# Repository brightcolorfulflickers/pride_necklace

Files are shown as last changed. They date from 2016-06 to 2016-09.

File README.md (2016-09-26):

# pride_necklace
A Neopixel necklace to celebrate LGBT pride.

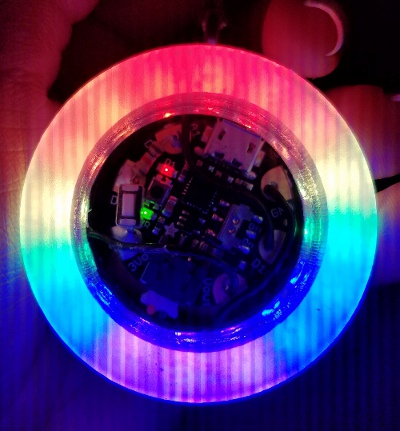
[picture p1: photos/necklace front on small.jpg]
Rainbow Flag Necklace


## Overview
I made this necklace to celebrate LGBT pride month. It's based on [this Adafruit tutorial](https://learn.adafruit.com/gemma-hoop-earrings/overview), but I modified it heavily. It adds a button so that the user can cycle through different animations. Full instructions are below.

Thank you to Adafruit for posting this project on their [blog](https://blog.adafruit.com/2016/06/26/a-neopixel-necklace-to-celebrate-lgbt-pride-her_nerdiness-pride2016/)!

## Tools Required

I used a laser cutter, a 3d printer, and a soldering iron.

## Parts Used

Electronic parts:
- [Adafruit Gemma](https://www.adafruit.com/product/1222)
- [16 Neopixel Ring](https://www.adafruit.com/product/1463)
- [150 mAh battery](https://www.adafruit.com/product/1317)
- [Slim button](https://www.adafruit.com/products/1489)
- 10k resistor
- 26 AWG stranded wire

Other parts:
- E6000 adhesive
- Acrylic: [3/16" clear](http://www.mcmaster.com/#8560K163), [1/8" clear](http://www.mcmaster.com/#8560K239), [1/8" frosted](http://www.ebay.com/itm/272185258220)
- PLA filament
- [Glue-on pendant bail](https://www.etsy.com/transaction/1154709693)
- Chain of your choice - buy at any craft store

## Instructions

For the electronic part, mostly follow the Adafruit tutorial linked above. However, I made the following modifications. Be sure to carefully measure out wire lengths so that there is a little slack on the wires but not too much.
- Solder D1 to Neopixel data in.
- Solder the button between 3V and D0.
- Solder the resistor between D0 and D2.
- Be sure to solder to the 5V on the Neopixel ring right under the "Power 5V DC" label and the ground to the ground right under the "Ground" label.

Upload the code: pridenecklace.ino. This version has the rainbow flag, but you can modify this to make your own flags. I've included code for the bisexual and trans pride flags as well; see prideoutfit.ino. The main limitation is the low memory of the Gemma.

Laser cut the following parts:
- Cut "necklace back.svg" on the 1/8" clear acrylic.
- Cut "necklace front.svg" -- one copy of the circle on the 1/8" frosted acrylic, and two copies of the circle on the 3/16" clear acrylic. (Or you can 3D print a diffuser instead - see below.)

These files were created in Inkscape. I simply used the dimensions provided by Adafruit, if you would like to re-create them.

3D print the 150 mAh battery case. I just did a "fast print" in Cura to generate my gcode. You can also 3D print a diffuser cover for the Neopixel ring. I created the files in OpenSCAD and they're parametric, so you can edit them if you want. V1 was my original print but the wire slots are too small and there's not enough room for the battery wires at the bottom, so V2 should be an improvement. Also, you don't have to glue it on - it should just press fit on.

Use the E6000 to glue the small round piece to the back of the Gemma. Glue the ring with cutouts for the solder joints to the back of the Neopixel ring. Allow that to set and dry overnight.

Next, glue the pendant bail to the acrylic on the back on the Neopixel ring. Be sure to line up the bail with the top pixel, which is between the Adafruit flower and the Data Input solder joint. Also glue the battery case to the back of the acrylic on the Gemma. Line up the top opening of the case with the flat top cutout of the acrylic.

Glue the two remaining clear acrylic circles together, and glue the frosted acrylic circle on top of that. Be sure to spread a thin, even layer of the glue. Be sure all three layers are well-aligned. Let dry for several hours.

Carefully spread glue on the top white part of the pixels on the ring. Press the 3-layer acrylic ring on top and let dry.

If you want, you can shorten the battery wires. Cut, re-solder, and heat shrink.

## Photos

Don't mind the weird lines! They're an artifact of the Neopixel refresh rate.

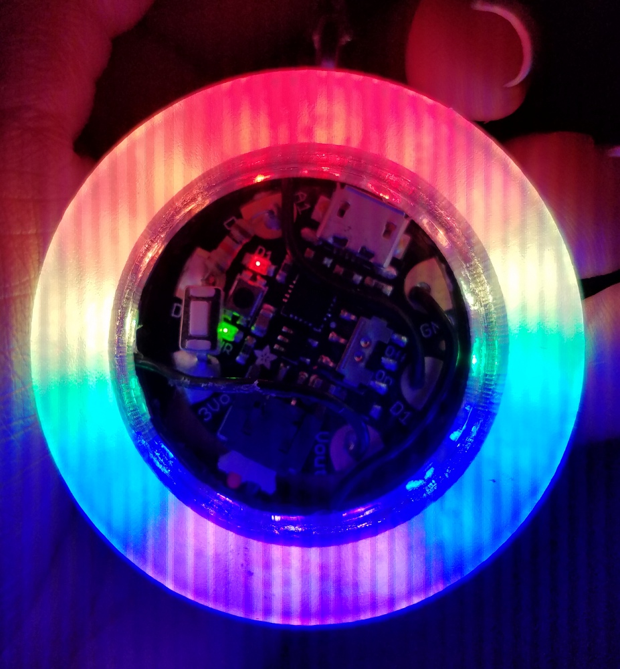
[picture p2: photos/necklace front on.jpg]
Rainbow Flag Necklace

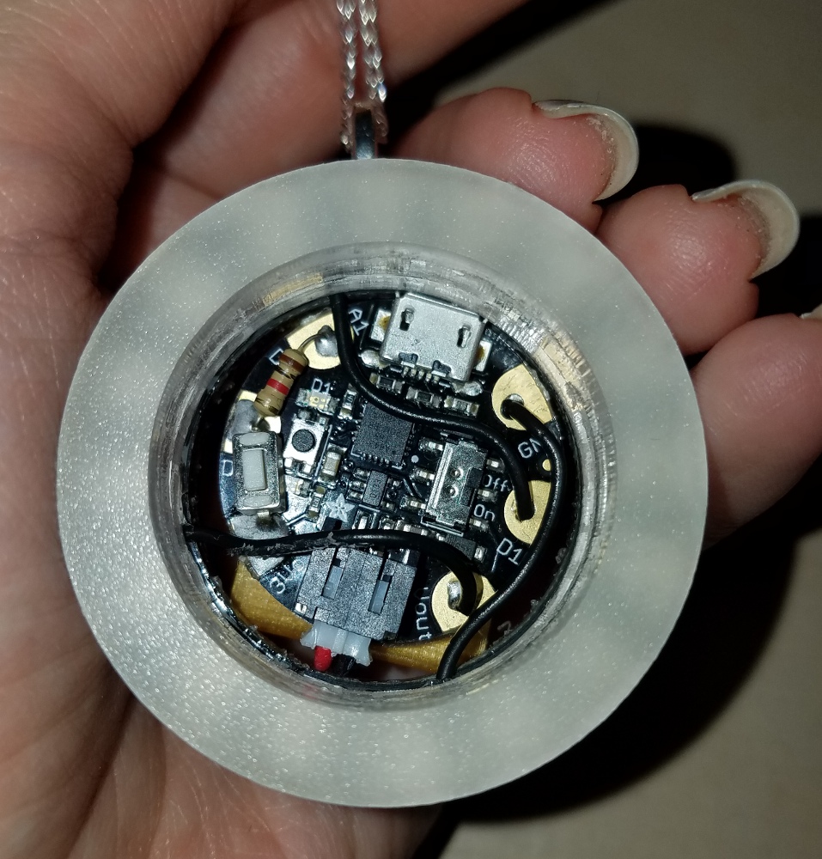
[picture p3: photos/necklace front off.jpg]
Rainbow Flag Necklace (off)

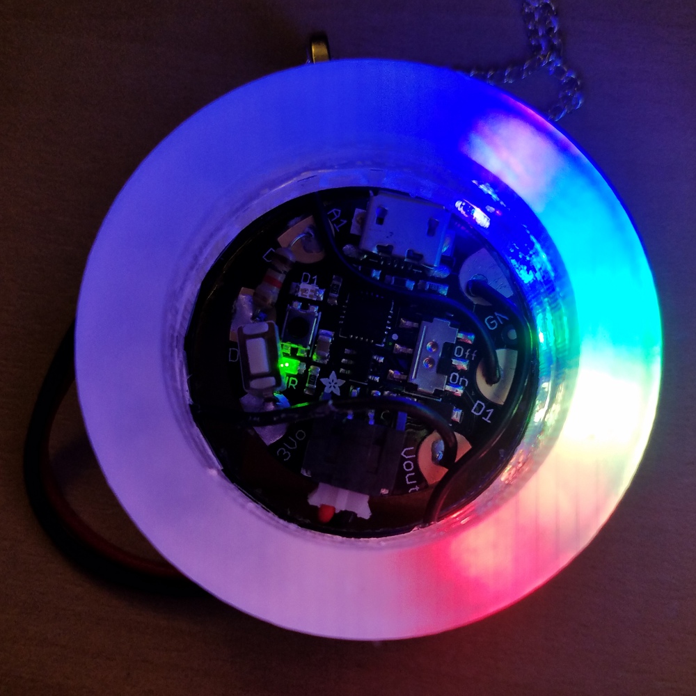
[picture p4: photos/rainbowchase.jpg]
Rainbow Flag Necklace (animation)

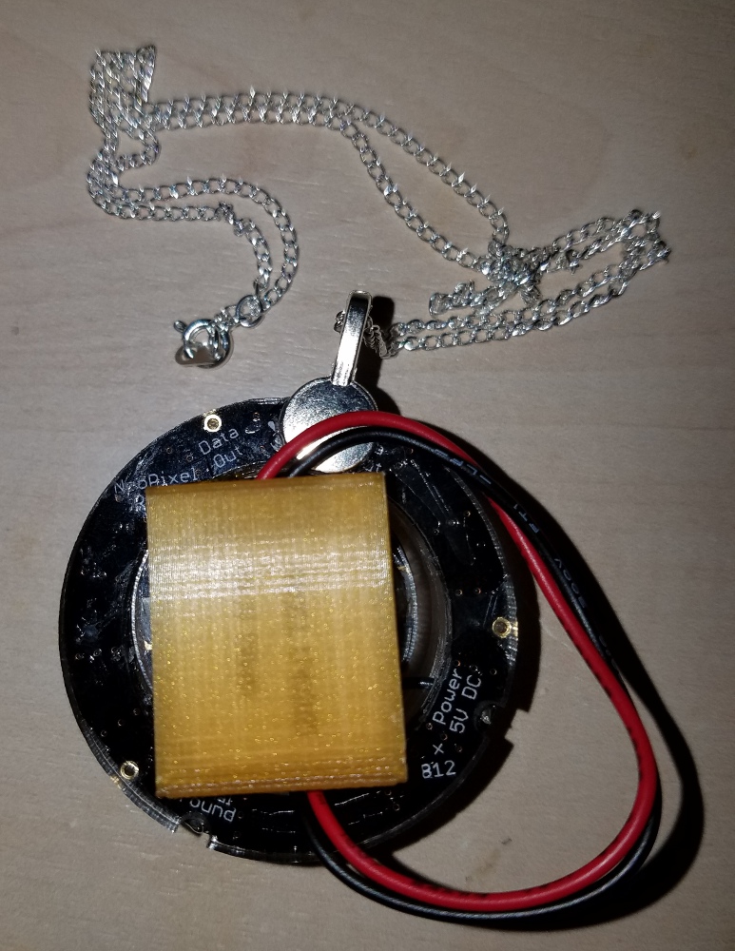
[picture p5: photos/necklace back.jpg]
Rainbow Flag Necklace (back)


For more process photos, see my [tumblr](http://brightcolorfulflickers.tumblr.com/tagged/pride-necklace).

## VARIANT: Pride Outfit

I also made a slightly more risqué version that I call the [pride outfit](http://brightcolorfulflickers.tumblr.com/tagged/pride-outfit). I used two Neopixel rings and a Gemma. I sewed the rings and Gemma into a cloth bikini with one ring on each side. That version uses the prideoutfit.ino code. Simply solder the two rings to the same pin and they will both receive the same data.

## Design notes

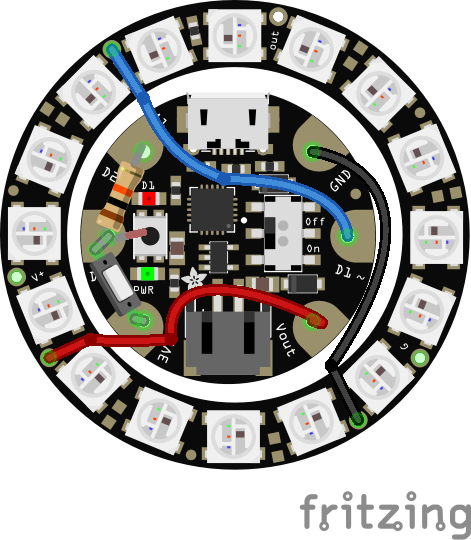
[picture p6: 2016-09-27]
schematic/pride necklace schematic.png

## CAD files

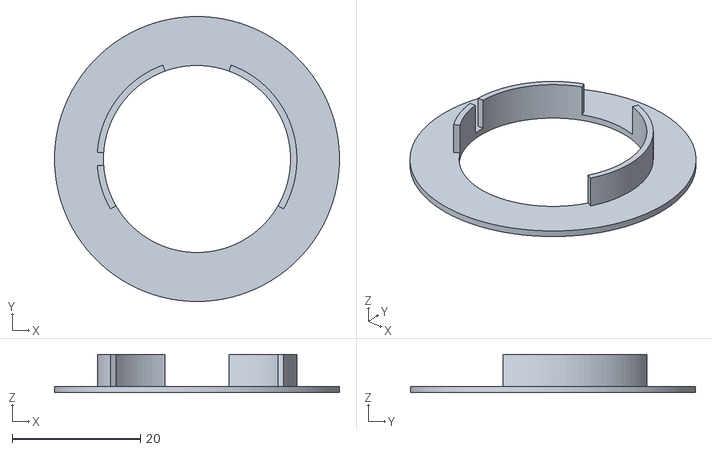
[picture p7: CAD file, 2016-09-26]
3dprint/16 neopixel cover v2.stl
44.5 x 44.5 x 6.00

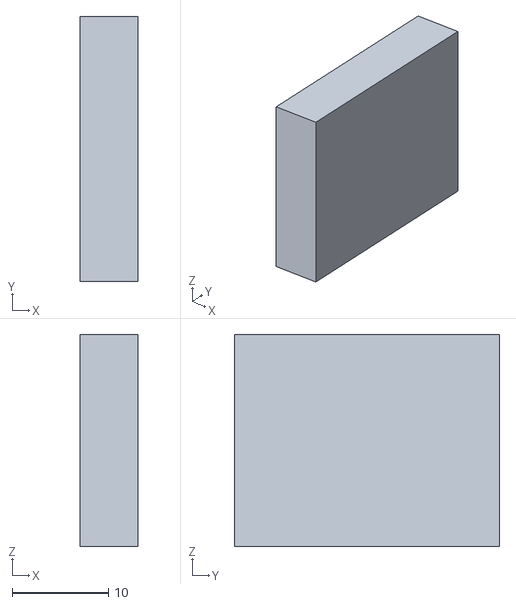
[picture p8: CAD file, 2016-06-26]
3dprint/150mAh battery case.stl
6.00 x 27.5 x 22.0

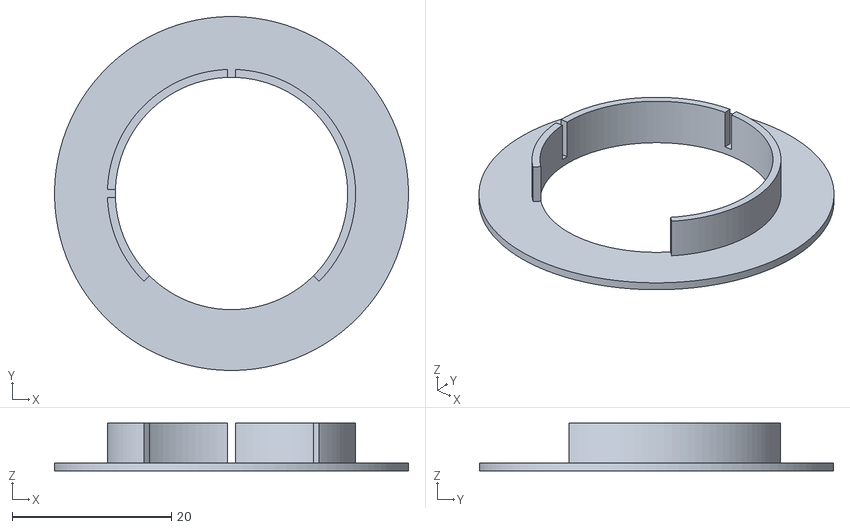
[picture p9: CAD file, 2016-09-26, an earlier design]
3dprint/16 neopixel cover v1.stl
44.5 x 44.5 x 6.00

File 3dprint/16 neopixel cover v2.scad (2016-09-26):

// This design is a cover for Adafruit's 16-Neopixel ring combined with the Gemma microcontroller into a necklace.
// Author: brightcolorfulflickers - instagram, tumblr, github
// September 2016

ring_h = 5; // height of the inner ring perpendicular to the PCB
outer_r = 44.5/2; // from OD posted on Adafruit product page
inner_r = 31.2/2; // from ID posted on Adafruit product page
case_ring_thick = 1; // thickness of the inner ring perpendicular to the PCB
case_top_thick = 1; // the thickness of the diffusion layer on top of the LEDs
wire_slot = 2; // width of slot for wires
top_cutout_angle = 60; // half sweep of top cutout (total is this x 2) since the Gemma presses up against the Neopixel ring
bottom_cutout_angle = 20; // half sweep of bottom cutout (total is this x 2) to allow space for battery & wire
fnval = 100; // resolution of render

module ring_case() {
    difference() {
        union() {
            translate([0,0,case_top_thick]) difference() {
            cylinder(ring_h,inner_r,inner_r, false, $fn=fnval);
            cylinder(ring_h,inner_r-case_ring_thick,inner_r-case_ring_thick, false, $fn=fnval);
            }

            difference() {
                cylinder(case_top_thick,outer_r,outer_r, false, $fn=fnval);
                cylinder(case_top_thick,inner_r-case_ring_thick,inner_r-case_ring_thick, false, $fn=fnval);
            }
        }
        //Cut out slots for the wires.
        translate([-wire_slot/2,0,case_top_thick]) cube([wire_slot,inner_r,ring_h], false);
        translate([-wire_slot/2,-inner_r,case_top_thick]) cube([wire_slot,inner_r,ring_h], false);
        
        translate([-inner_r,-wire_slot/2,case_top_thick]) cube([inner_r,wire_slot,ring_h], false);
    }
}

/* 
 * Excerpt from... 
 * 
 * Parametric Encoder Wheel 
 *
 * by Alex Franke (codecreations), March 2012
 * http://www.theFrankes.com
 * 
 * Licenced under Creative Commons Attribution - Non-Commercial - Share Alike 3.0 
*/
 
module arc( height, depth, radius, degrees ) {
    // This dies a horible death if it's not rendered here 
    // -- sucks up all memory and spins out of control 
    render() {
        difference() {
            // Outer ring
            rotate_extrude($fn = 100)
                translate([radius - height, 0, 0])
                    square([height,depth]);
         
            // Cut half off
            translate([0,-(radius+1),-.5]) 
                cube ([radius+1,(radius+1)*2,depth+1]);
         
            // Cover the other half as necessary
            rotate([0,0,180-degrees])
            translate([0,-(radius+1),-.5]) 
                cube ([radius+1,(radius+1)*2,depth+1]);
         
        }
    }
}

difference() {
    ring_case();
    //This part cuts out the top arc since the Gemma presses against the Neopixel ring. Widened from v1.
    translate([0,0,case_top_thick]) arc(case_ring_thick,ring_h,inner_r,top_cutout_angle);
    translate([0,0,case_top_thick]) mirror([1,0,0]) arc(case_ring_thick,ring_h,inner_r,top_cutout_angle);
    
    //This part cuts out the bottom arc to allow room for the battery wires.
    translate([0,0,case_top_thick]) mirror([0,1,0]) arc(case_ring_thick,ring_h,inner_r,bottom_cutout_angle);
    translate([0,0,case_top_thick]) mirror([1,0,0]) arc(case_ring_thick,ring_h,inner_r,-bottom_cutout_angle);
    
    
}

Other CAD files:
3dprint/16 neopixel cover v1.scad

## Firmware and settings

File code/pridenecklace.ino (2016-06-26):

/*
 * LGBT Pride Necklace
 * by brightcolorfulflickers
 * June 2016
 *
 * github.com/brightcolorfulflickers
 * brightcolorfulflickers.tumblr.com
 * instagram.com/brightcolorfulflickers
 */

#include <Adafruit_NeoPixel.h>
#ifdef __AVR__
  #include <avr/power.h>
#endif

#define LED_PIN 1
#define BUTTON 0
#define GNDPIN 2
#define NUM_LEDS 16
int modeCount = 0;
const byte numModes = 4;

long lastButtonCheck = 0;
const long buttonDebounceTime = 200; //200 ms
bool firstUpdate = false;

byte buttonFlag;//this flag is used to communicate to the main loop that a new value was read.

Adafruit_NeoPixel strip = Adafruit_NeoPixel(NUM_LEDS, LED_PIN, NEO_GRB + NEO_KHZ800);

uint32_t black;
uint32_t red;
uint32_t orange;
uint32_t yellow;
uint32_t green;
uint32_t blue;
uint32_t purple;

void setup() {
  strip.begin();
  strip.setBrightness(60);
  strip.show(); // Initialize all pixels to 'off'
  pinMode(BUTTON, INPUT);
  pinMode(GNDPIN, OUTPUT);
  digitalWrite(GNDPIN, LOW);

  //define colors
  black = strip.Color(0, 0, 0);
  red = strip.Color(255, 0, 0);
  orange = Wheel(10);
  yellow = strip.Color(255, 255, 0);
  green = strip.Color(0, 255, 0);
  blue = strip.Color(0, 0, 255);
  purple = Wheel(193);
}

void loop() {
  //if debounce time has passed, check button
  if ((unsigned long)(millis() - lastButtonCheck) > buttonDebounceTime) {
    int buttonRead = digitalRead(BUTTON);
    if (buttonRead == HIGH) {
      buttonFlag = 1; //set the flag that tells the loop() that a button was pushed
    }
    lastButtonCheck = millis();
  }

  //if button has been pressed, update the display (or if it's never been set)
  if (buttonFlag == 1 || firstUpdate == false) {
    buttonFlag = 0; //clear button press
    if (firstUpdate == false) {
      firstUpdate = true; //the first update has occurred
    }
    else { // otherwise, increment mode counter as usual
      modeCount++;

    }


  }
  if (modeCount % numModes == 0) {
    rainbowFlagDisplay();
    //Serial.println("Display Flag");
  }
  else if (modeCount % numModes == 1) {
    rainbowFlagRotate(200);
  }
  else if (modeCount % numModes == 2) {
    rainbowColorChase(100);
  }
  else if (modeCount % numModes == 3) {
    rainbowCycle(40);
  }


}

// Slightly different, this makes the rainbow equally distributed throughout
void rainbowCycle(uint8_t wait) {
  uint16_t i, j;

  for(j=0; j<256*5; j++) { // 5 cycles of all colors on wheel
    for(i=0; i< strip.numPixels(); i++) {
      strip.setPixelColor(i, Wheel(((i * 256 / strip.numPixels()) + j) & 255));
    }
    strip.show();

    //we need to check the button in here because of the delay
    long startWait = millis();
    while ((unsigned long)(millis() - startWait) < wait) {
      if ((unsigned long)(millis() - lastButtonCheck) > buttonDebounceTime) {
        int buttonRead = digitalRead(BUTTON);
        lastButtonCheck = millis();
        if (buttonRead == HIGH) {
          buttonFlag = 1; //set the flag that tells the loop() that a button was pushed
          return; //return to the main loop to change the mode
        }
      }
    }
    //not using delays
    //delay(wait);
  }
}

void rainbowFlagDisplay() {
  uint16_t i;

  uint32_t rainbowFlag[NUM_LEDS] = {red, red, red, orange,orange, yellow, green, blue, purple, purple, purple, blue, blue, green, yellow, orange};

  for(i=0; i<strip.numPixels(); i++) {
    strip.setPixelColor(i, rainbowFlag[i]);
  }
  strip.show();
}

void rainbowFlagRotate(uint8_t wait) {
  uint16_t i;
  uint16_t j;

  uint32_t rainbowFlag[NUM_LEDS] = {red, red, red, orange,orange, yellow, green, blue, purple, purple, purple, blue, blue, green, yellow, orange};

  for (j=0; j<strip.numPixels(); j++) {
    for(i=0; i<strip.numPixels(); i++) {
      strip.setPixelColor(i, rainbowFlag[(i+j) % NUM_LEDS]);
    }
    strip.show();
    //we need to check the button in here because of the delay
    long startWait = millis();
    while ((unsigned long)(millis() - startWait) < wait) {
      if ((unsigned long)(millis() - lastButtonCheck) > buttonDebounceTime) {
        int buttonRead = digitalRead(BUTTON);
        lastButtonCheck = millis();
        if (buttonRead == HIGH) {
          buttonFlag = 1; //set the flag that tells the loop() that a button was pushed
          return; //return to the main loop to change the mode
        }
      }
    }
    //not using delays
//    delay(wait);
  }
}

void rainbowColorChase(uint8_t wait) {
  uint16_t i;
  uint16_t j;

  uint32_t rainbowChase[NUM_LEDS] = {red, orange, yellow, green, blue, purple, black, black, black, black, black, black, black, black, black, black};

  for (j=0; j<strip.numPixels(); j++) {
    for(i=0; i<strip.numPixels(); i++) {
      strip.setPixelColor(i, rainbowChase[(i+j) % NUM_LEDS]);
    }
    strip.show();
        //we need to check the button in here because of the delay
    long startWait = millis();
    while ((unsigned long)(millis() - startWait) < wait) {
      if ((unsigned long)(millis() - lastButtonCheck) > buttonDebounceTime) {
        int buttonRead = digitalRead(BUTTON);
        lastButtonCheck = millis();
        if (buttonRead == HIGH) {
          buttonFlag = 1; //set the flag that tells the loop() that a button was pushed
          return; //return to the main loop to change the mode
        }
      }
    }
    //not using delays
    //delay(wait);
  }
}


// Input a value 0 to 255 to get a color value.
// The colours are a transition r - g - b - back to r.
uint32_t Wheel(byte WheelPos) {
  WheelPos = 255 - WheelPos;
  if(WheelPos < 85) {
    return strip.Color(255 - WheelPos * 3, 0, WheelPos * 3);
  }
  if(WheelPos < 170) {
    WheelPos -= 85;
    return strip.Color(0, WheelPos * 3, 255 - WheelPos * 3);
  }
  WheelPos -= 170;
  return strip.Color(WheelPos * 3, 255 - WheelPos * 3, 0);
}

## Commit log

2016-06-26 pride necklace v1
    [150mAh battery case.stl]
2016-08-23 Fixed bi pride overflow
    An overflow error caused the animations to glitch out after 2^16 milliseconds. I believe it is fixed now - at least for the bi pride version. I still need to correct the other files.
    [bipride.ino]
2016-08-24 Fixed animation/mode changing errors
    Bi Pride:
    -Added color flash mode indicator when the user clicks to switch modes
    -Corrected error which prevented switching modes correctly when in random mode
    Pride Outfit (trans + bi)
    -Fixed overflow error causing animation glitches
    [bipride.ino, prideoutfit.ino]
2016-09-26 3d printed diffuser
    Instead of using so much acrylic, you can print a diffuser from white PLA that's 1 mm thick.
    [16 neopixel cover v1.scad, 16 neopixel cover v1.stl, 16 neopixel cover v2.scad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]
2016-09-26 3d printed diffuser - readme
    Updated readme to include new 3d printed diffuser
2016-09-27 Added schematic
    [pride necklace.fzz]
2016-09-28 animation fix
    The intDelay function seemed to not work when I re-uploaded the code to my necklace, resulting in no animations, so I fixed the error.
    [bipride.ino, panpride.ino]
